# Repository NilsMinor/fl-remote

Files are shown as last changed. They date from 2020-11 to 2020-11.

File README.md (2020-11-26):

# FireLight Remote
A smart bluetooth low energy remote based on a nrf52 module with touch keys and a gyro sensor.

| Top view  | Bottom view  |
|---|---|
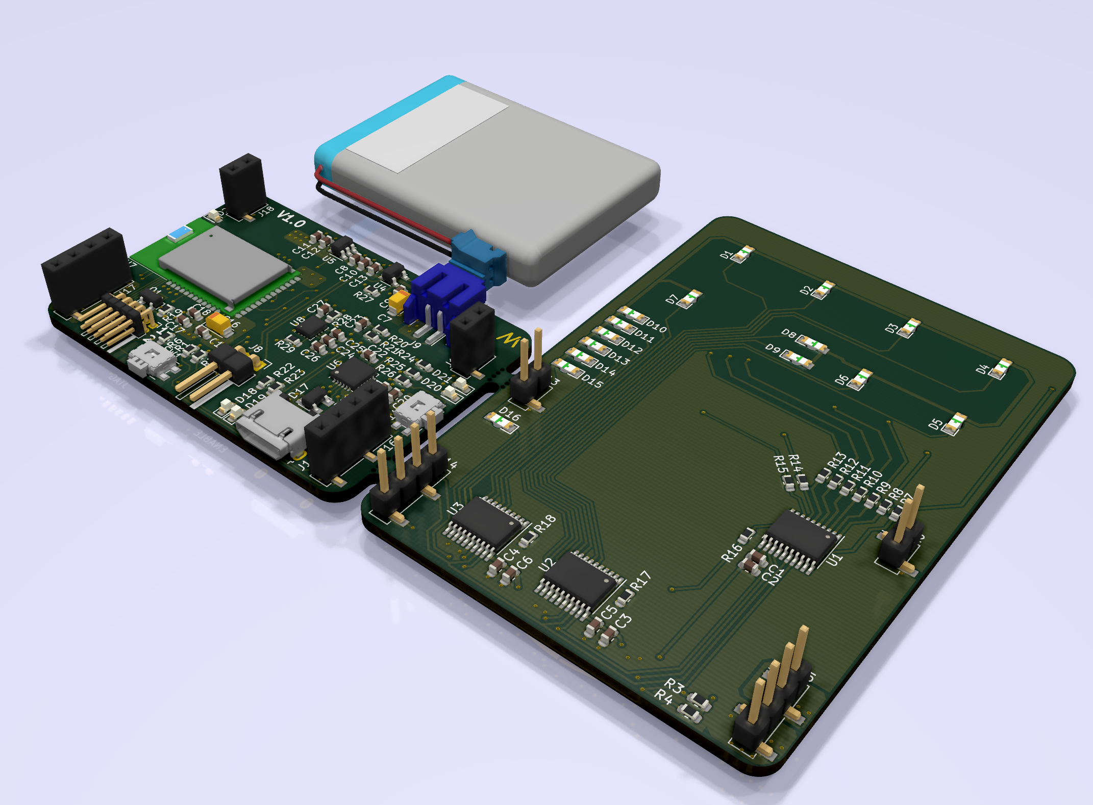
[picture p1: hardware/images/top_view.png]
Top view
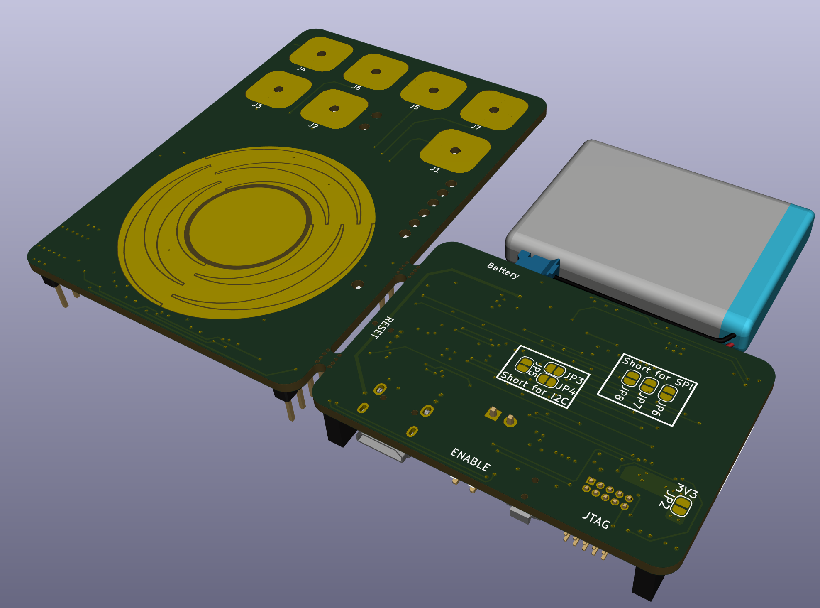
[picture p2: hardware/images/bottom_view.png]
Bottom view
|  | |

## Introduction
This board is based on a nrf52832 module from Minew (MS50SFB). It is designed as a remote to support the FireLight mesh as a special control node. However, as it is a normal nrf52 chipset it also supports Zephyr or other IoT frameworks. Checkout the nordic website for more software information.

## Features

The board comes with the following features:
- Small overall design (53 mm x 75 mm x 12 mm)
- Single PCB design with panel break off tabs
- nrf52832 module (MS50SFB) with onboard antenna
- 7 touch keys with 3 channel touch wheel based on the AT42QT2120
- 16 reverse mounted LEDs powerd by two TLC59108
- ICM-20600 6-Axis MEMS Motion tracking sensor 
- CP2104 USB to Uart converter
- Integrated single cell LiPo Charger (MCP73832)
- Most pats from JLCPCB parts library

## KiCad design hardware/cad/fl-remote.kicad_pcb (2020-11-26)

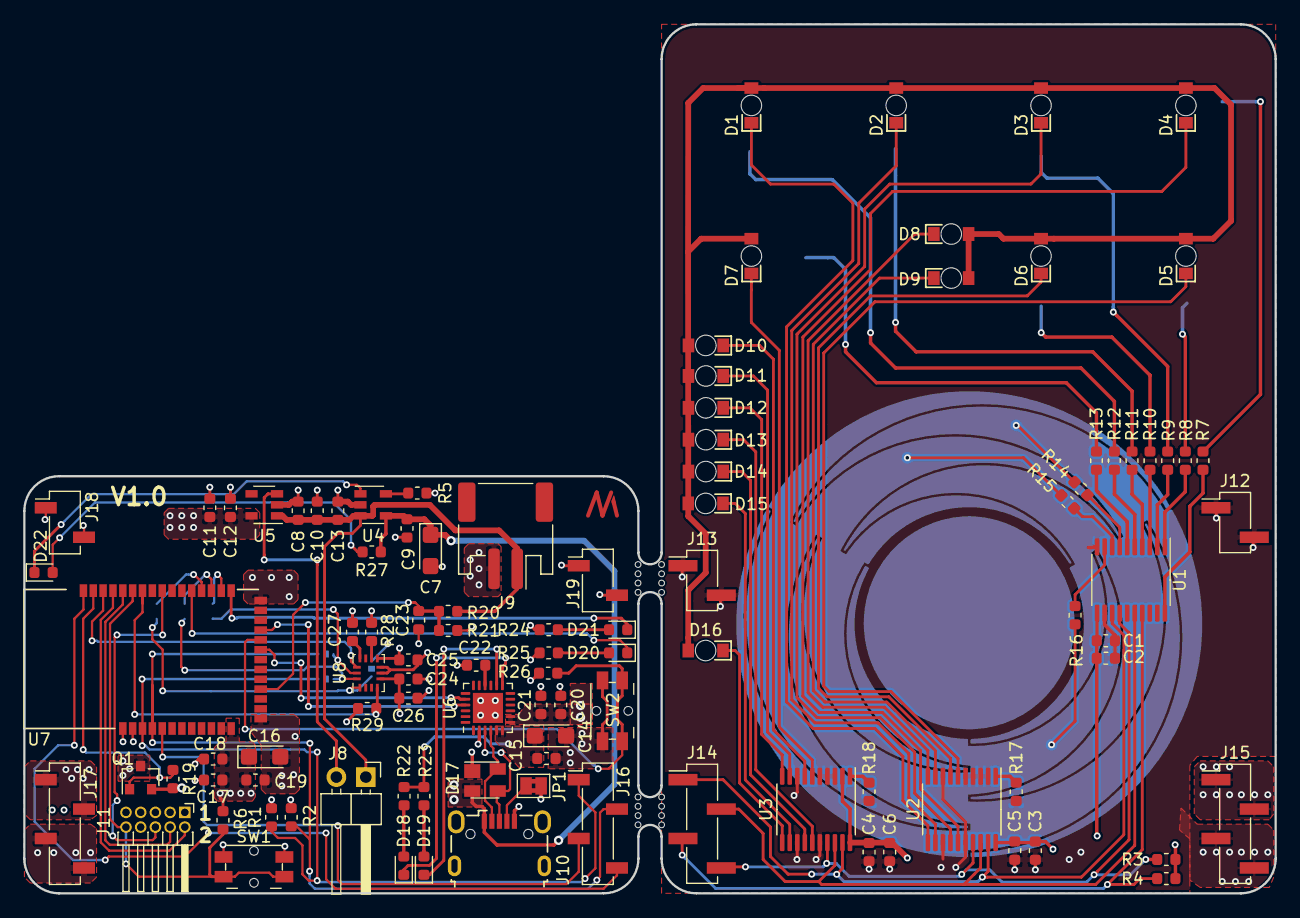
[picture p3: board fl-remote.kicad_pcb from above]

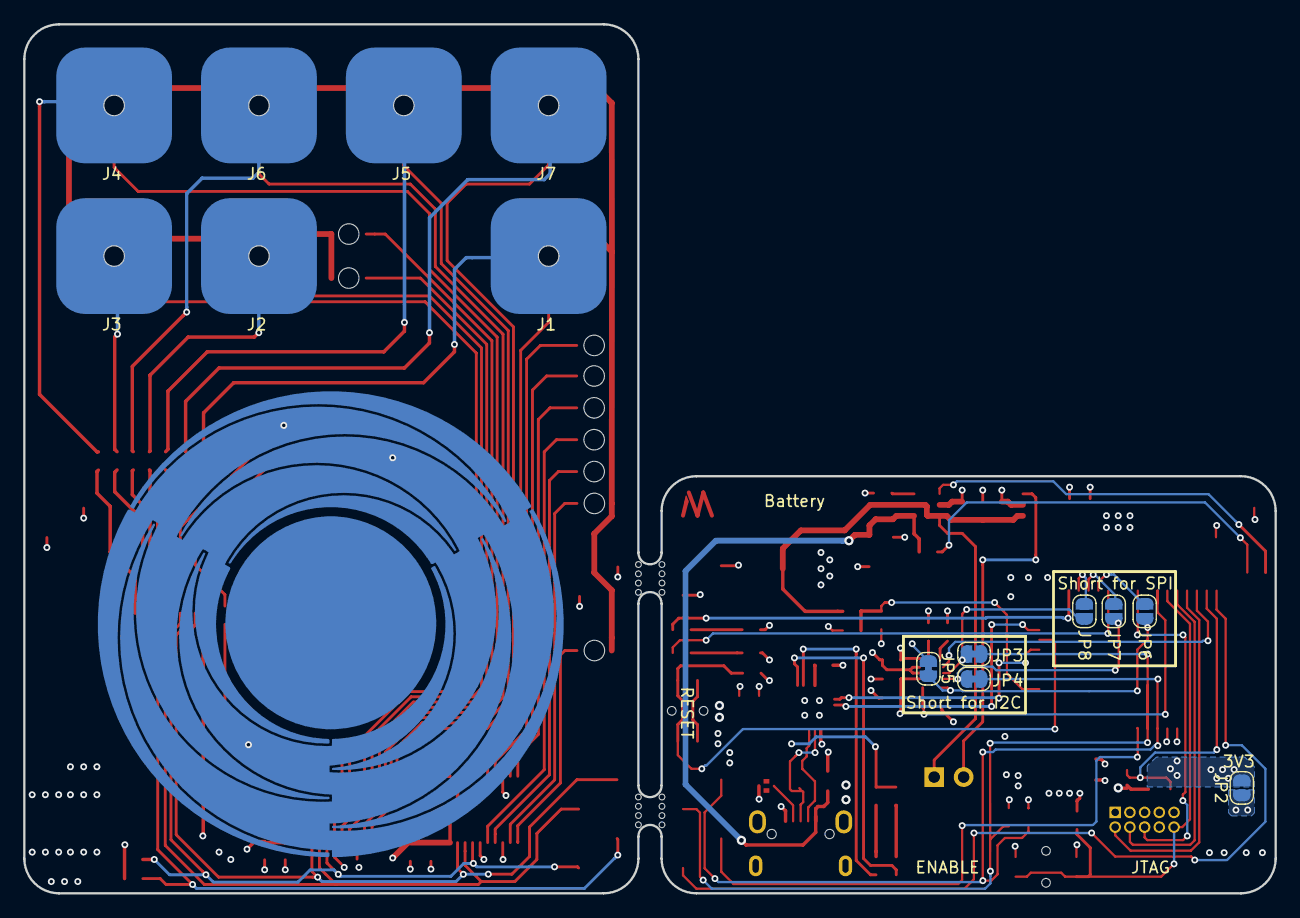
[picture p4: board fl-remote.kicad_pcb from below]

Board: 4 copper layers, 108.0 x 75.0 mm, 117 parts (14 on the bottom side), 87 nets.

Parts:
C1, C3, C4, C8, C11, C13, C17, C18, C20, C22, C25: 10u; C_0603_1608Metric
C2, C5, C6, C9, C10, C12, C15, C19, C21, C24, C26: 100n; C_0603_1608Metric
C7, C14, C16: 10u; CP_EIA-3216-18_Kemet-A
C23: 1n; C_0603_1608Metric
C27: 10n; C_0603_1608Metric
D1, D2, D3, D4, D5, D6, D7, D8, D9, D10, D11, D12, D13, D14, D15, D16: LED; 156125BS57000
D17: SP0503BAHT; SOT-143
D18, D19, D20, D21, D22: LED; LED_0603_1608Metric
J1, J2, J3, J4, J5, J6, J7: Conn_01x01_Male; Touchpad
J8: Conn_01x02_Male; PinHeader_1x02_P2.54mm_Horizontal
J9: Conn_01x02_Female; JST_PH_S2B-PH-SM4-TB_1x02-1MP_P2.00mm_Horizontal
J10: USB_B_Micro; USB_Micro-B_Wuerth_629105150521
J11: Conn_02x05_Odd_Even; PinHeader_2x05_P1.27mm_Horizontal
J12, J13: Conn_01x02_Male; PinHeader_1x02_P2.54mm_Vertical_SMD_Pin1Left
J14, J15: Conn_01x04_Male; PinHeader_1x04_P2.54mm_Vertical_SMD_Pin1Left
J16, J17: Conn_01x04_Female; PinSocket_1x04_P2.54mm_Vertical_SMD_Pin1Left
J18, J19: Conn_01x02_Female; PinSocket_1x02_P2.54mm_Vertical_SMD_Pin1Left
JP1: Jumper_NC_Small; SolderJumper-2_P1.3mm_Bridged2Bar_Pad1.0x1.5mm
JP2, JP6, JP7, JP8: Jumper_NO_Small; SolderJumper-2_P1.3mm_Open_RoundedPad1.0x1.5mm
JP3, JP4, JP5: Jumper_NC_Small; SolderJumper-2_P1.3mm_Bridged_RoundedPad1.0x1.5mm
Q1: Q_PMOS_GSD; SOT-23
R1, R2, R3, R4, R6, R7, R8, R9, R10, R11, R12, R13, R14, R15, R16, R26: 4k7; R_0603_1608Metric
R5: 2k; R_0603_1608Metric
R17, R18: 750R; R_0603_1608Metric
R19, R28, R29: 10k; R_0603_1608Metric
R20: 806k; R_0603_1608Metric
R21: 2M; R_0603_1608Metric
R22, R23, R27: 1k; R_0603_1608Metric
R24, R25: 1k6; R_0603_1608Metric
SW1, SW2: SW_Push; Panasonic_EVQPUL_EVQPUC
U1: AT42QT2120-XU; TSSOP-20_4.4x6.5mm_P0.65mm
U2, U3: TLC59108xPW; TSSOP-20_4.4x6.5mm_P0.65mm
U4: MCP73832-2-OT; SOT-23-5
U5: AP2112K-3.3; SOT-23-5
U6: CP2104; QFN-24-1EP_4x4mm_P0.5mm_EP2.6x2.6mm
U7: MS50SFB2
U8: ICM-20600; Bosch_LGA-14_3x2.5mm_P0.5mm
U9: Logo_NM

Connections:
+3V3: C11.1, C12.2, C16.1, C17.1, C18.1, C19.2, C24.2, C25.1, C26.2, J11.1, JP2.1, Q1.2, R1.2, R2.2, R6.2, R19.2, R24.2, R25.2, R26.2, R28.2, R29.2, U5.5, U7.12, U8.5, U8.8
/B_3V3: J17.1, J17.2, JP2.2, Q1.3
/B_SCL: J16.2, JP4.2, R2.1, U7.4
/B_SDA: J16.1, JP3.2, R1.1, U7.3
/INT1: R29.1, U7.35, U8.4
/INT2: R28.1, U8.9
/MISO: JP6.2, U7.29
/MOSI: JP7.2, U7.28
/SCLK: JP8.2, U7.27
/T_GND: C1.2, C2.2, C3.2, C4.2, C5.2, C6.2, J12.1, J12.2, J13.1, J13.2, J15.3, J15.4, R17.1, R18.1, U1.10, U1.12, U2.2, U2.3, U2.4, U2.5, U2.8, U2.13, U2.16, U3.3, U3.4, U3.5, U3.8, U3.13, U3.16
/T_SCL: J14.2, U1.16, U2.18, U3.18
/T_SDA: J14.1, U1.13, U2.19, U3.19
/T_VDD: C1.1, C2.1, C3.1, C4.1, C5.1, C6.1, J15.1, J15.2, R3.2, R4.2, U1.11, U2.20, U3.2, U3.20
/ble/AIN0: C23.1, R20.1, R21.2, U7.16
/ble/D9: D20.1, U7.30
/ble/D10: D21.1, U7.26
/ble/D11: R26.1, SW2.1, U7.21
/ble/P18: J11.6, U7.33
/ble/P21: J11.10, R6.1, SW1.1, U7.36
/ble/RXD: U6.21, U7.22
/ble/SWCLK: J11.4, U7.37
/ble/SWDIO: J11.2, U7.38
/imu/AD0_SDO: JP5.1, JP6.1, U8.1
/imu/SCL_SCLK: JP4.1, JP8.1, U8.13
/imu/SDA_SDI: JP3.1, JP7.1, U8.14
/power/EN: J8.2, U5.3
/power/VBAT: C8.1, C10.2, C13.1, J8.1, J9.1, R20.2, U4.3, U5.1
/touch/KEY3: J1.1, R13.1
/touch/KEY4: J7.1, R12.1
/touch/KEY5: J5.1, R11.1
/touch/KEY6: J2.1, R10.1
/touch/KEY7: J6.1, R9.1
/touch/KEY8: J3.1, R8.1
/touch/KEY9: J4.1, R7.1
/usb_to_uart/RXD_I: U6.20, U7.20
/usb_to_uart/USB_D+: D17.3, J10.3, U6.3
/usb_to_uart/USB_D-: D17.4, J10.2, U6.4
/~B_CHANGE: J16.3, U7.5
/~B_RESET: J16.4, U7.41
/~CS: U7.39, U8.12
/~ENABLE_3V3: Q1.1, R19.1, U7.40
/~T_CHANGE: J14.3, R4.1, U1.17
/~T_RESET: J14.4, R3.1, U1.14, U2.17, U3.17
GND: C7.2, C8.2, C9.1, C10.1, C11.2, C12.1, C13.2, C14.2, C15.1, C16.2, C17.2, C18.2, C19.1, C20.2, C21.1, C22.2, C23.2, C24.1, C25.2, C26.1, C27.1, D17.1, J9.2, J10.5, J10.6, J11.3, J11.5, J11.7, J11.9, J17.3, J17.4, J18.1, J18.2, J19.1, J19.2, JP1.2, JP5.2, R5.1, R21.1, SW1.2, SW2.2, U4.2, U5.2, U6.2, U6.25, U7.1, U7.2, U7.13, U7.25, U8.6, U8.7
unnamed: C22.1, U6.16
unnamed: C27.2, U8.11
unnamed: D1.1, U2.11
unnamed: D2.1, U2.12
unnamed: D3.1, U2.14
unnamed: D4.1, U2.15
unnamed: D5.1, U2.6
unnamed: D6.1, U2.7
unnamed: D7.1, U3.6
unnamed: D8.1, U2.10
unnamed: D9.1, U2.9
unnamed: D10.1, U3.7
unnamed: D11.1, U3.9
unnamed: D12.1, U3.10
unnamed: D13.1, U3.15
unnamed: D14.1, U3.14
unnamed: D15.1, U3.12
unnamed: D16.1, U3.11
unnamed: D18.1, U6.13
unnamed: D18.2, R22.1
unnamed: D19.1, U6.14
unnamed: D19.2, R23.1
unnamed: D20.2, R24.1
unnamed: D21.2, R25.1
unnamed: D22.1, U4.1
unnamed: D22.2, R27.1
unnamed: J10.4, JP1.1
unnamed: R5.2, U4.5
unnamed: R7.2, U1.20
unnamed: R8.2, U1.1
unnamed: R9.2, U1.2
unnamed: R10.2, U1.3
unnamed: R11.2, U1.4
unnamed: R12.2, U1.5
unnamed: R13.2, U1.6
unnamed: R14.2, U1.7
unnamed: R15.2, U1.8
unnamed: R16.2, U1.9
unnamed: R17.2, U2.1
unnamed: R18.2, U3.1
VAA: C14.1, C15.2, R22.2, R23.2, U6.5, U6.6
VBUS: C7.1, C9.2, C20.1, C21.2, D17.2, J10.1, R27.2, U4.4, U6.7, U6.8
VD: D1.2, D2.2, D3.2, D4.2, D5.2, D6.2, D7.2, D8.2, D9.2, D10.2, D11.2, D12.2, D13.2, D14.2, D15.2, D16.2
